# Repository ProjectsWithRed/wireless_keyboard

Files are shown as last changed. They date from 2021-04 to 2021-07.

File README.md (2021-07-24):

# Arduino custom wireless keyboard

There is a [video](https://youtu.be/N5rOW5Bu1kc) associated with this repo, I highly recommend you watch it if you are going to use this repo.

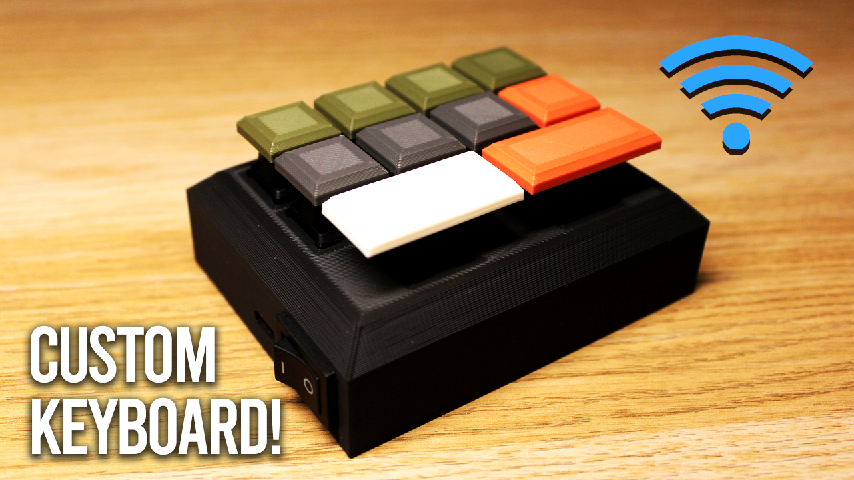
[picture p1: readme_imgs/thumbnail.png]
Video (https://youtu.be/N5rOW5Bu1kc "Arduino wireless keyboard")


# How to use

## Libraries needed

*Installed directly from the Arduino library manager.

- `RF24` by TMRh20.
- `Button` by Michael Adams.

## For the transmitter

- This is the micro-controller (MC) that will be running on battery and where all the buttons will be connected to. This needs to be a low current consuming MC and one that ideally meets the number of inputs pins to match the number buttons you are going to have.
- I highly recommend the Attiny MCs, such as the Attiny85 (8 pins), Attiny84 (14 pins), or the Attiny88 (28 pins).
- Changes you need to make to the code (`/transmitter`):
    - The `CE and CSN` pin numbers to match your connections, these could be any GPIO pins in your MC.
    - `MAX_SHORTCUT_KEYS`, this is the maximum number of characters a keyboard shortcut/sequence can be. This is specified so only the required number of bytes are sent through the radio signal.
    - The `BUTTONS_INFO` array. Each button element is made up of two values, the first is the pin number the button is connected to your MC. The second is a string of characters seperated by spaces. The characters are represented by their decimal/int values, which can be found [here](http://www.asciitable.com/) and [here](https://www.arduino.cc/reference/en/language/functions/usb/keyboard/keyboardmodifiers/). Make sure you don't go over your `MAX_SHORTCUT_KEYS` in the string of keys, if more keys are required, simply increase `MAX_SHORTCUT_KEYS`.

## For the Receiver

- Any MC can be used here with USB cable connection, and one that has HID support so you can easily use the Arduino Keyboard library with no issues. I recommend the Pro Micro MC.
- Changes you need to make to the code (`/receiver`):
    - The only change you need to make is if you changed the `MAX_SHORTCUT_KEYS` in the transmitter side, if you did, make sure the `MAX_SHORTCUT_KEYS` matches.

## For 3D printing

Please refer to the `/3d_models` directory.

# Components

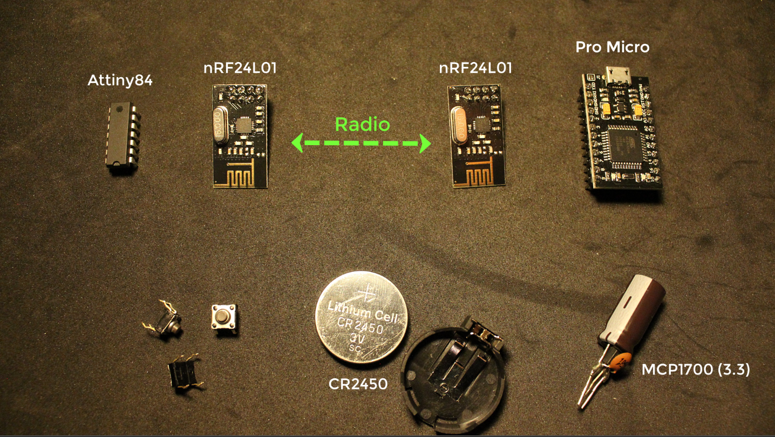
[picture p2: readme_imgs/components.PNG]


# Wiring

## Transmitter
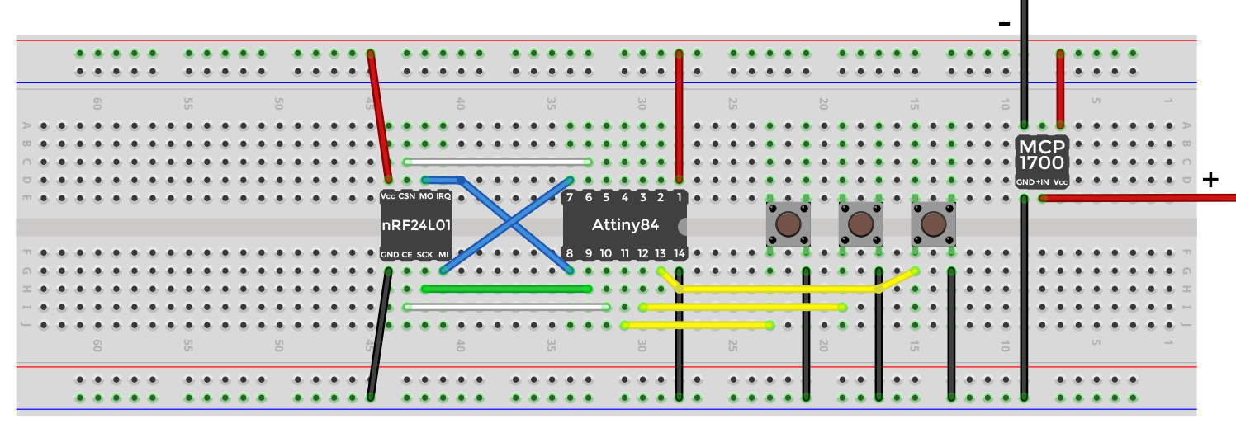
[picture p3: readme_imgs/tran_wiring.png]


## Receiver
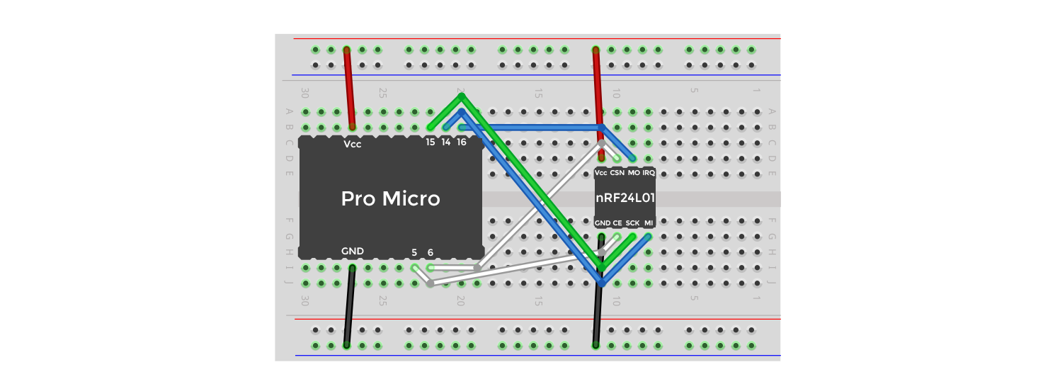
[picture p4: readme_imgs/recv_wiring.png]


# How to upload code to Attiny MCs

- The Attiny MCs can be programmed just like any Arduino and it's very easy to upload code to them.
- You just need a USBASP adapter, then simply make the connections as shown in the image below.

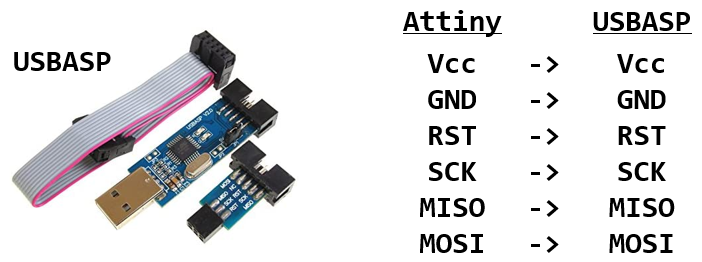
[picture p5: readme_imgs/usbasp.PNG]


- You will also need to install the Attiny boards using the [AttinyCore](https://github.com/SpenceKonde/ATTinyCore) board manager by placing this link `http://drazzy.com/package_drazzy.com_index.json` to your "Additional Boards Manager URLs", which can be accessed in `File > Preferences`.

- From `Tools > Board`, choose your Attiny board with the no bootloader option.
- Then go to `Tools > Programmer` and choose `USBasp (ATTinyCore)`, and then press `Tools > Burn Bootloader`.
- Then to simply upload code, use `Sketch > Upload Using Programmer`.

- You can use stripboards with some wires to make uploading code to the Attiny MCs more convenient:

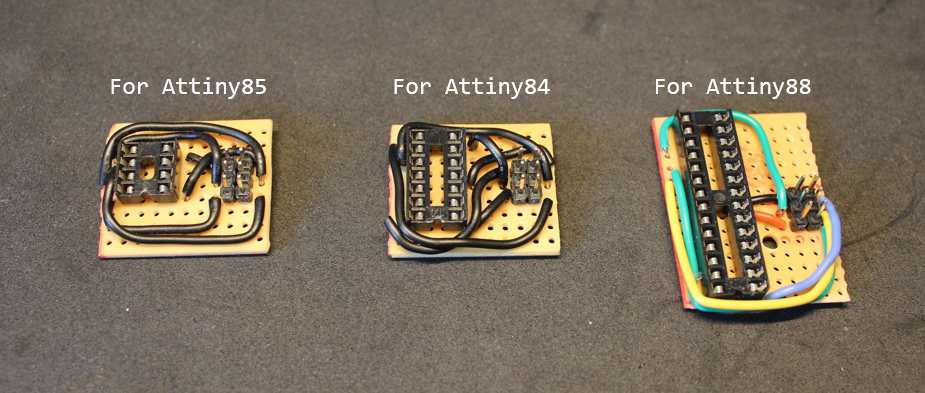
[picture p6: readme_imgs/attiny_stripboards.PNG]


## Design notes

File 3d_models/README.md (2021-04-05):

# 3D models

Please note, these models only work for MX Cherry switches.

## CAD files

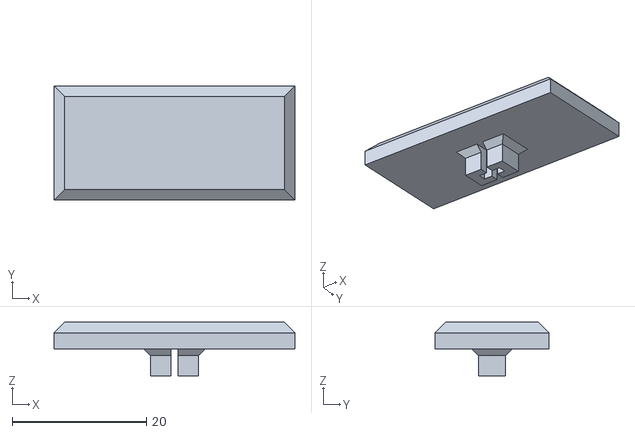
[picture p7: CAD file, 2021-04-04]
3d_models/keyCap_2x1.stl
35.9 x 17.0 x 8.00

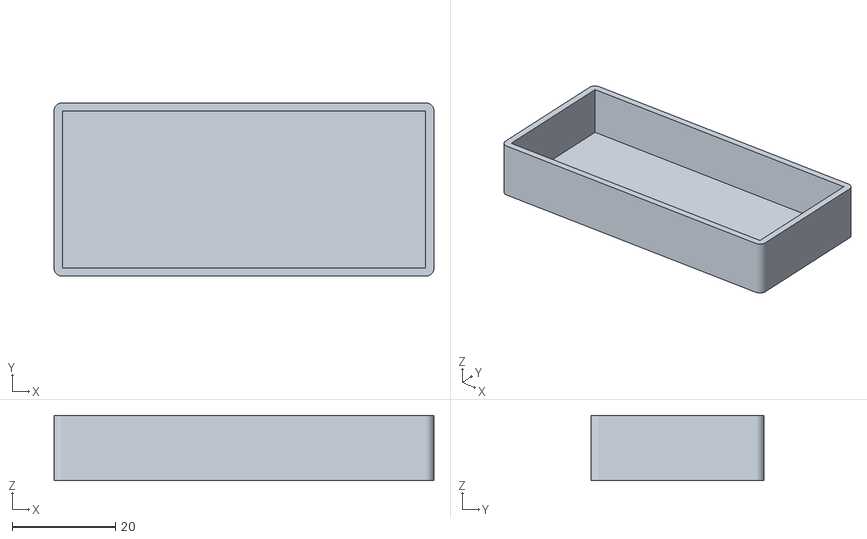
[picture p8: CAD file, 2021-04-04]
3d_models/recv_housing.stl
73.6 x 33.6 x 12.6

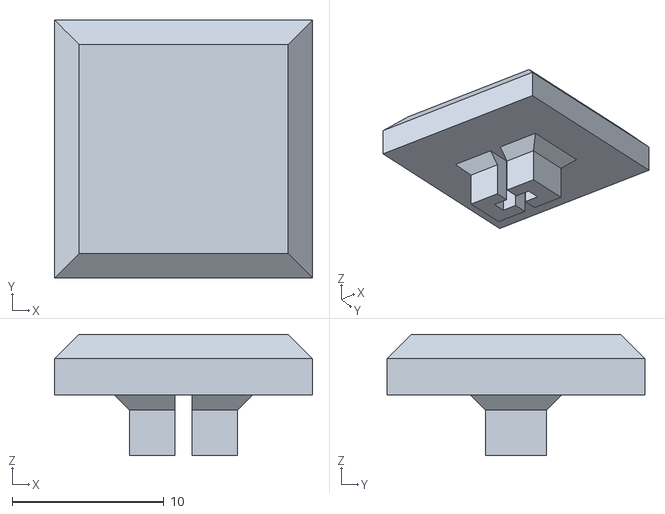
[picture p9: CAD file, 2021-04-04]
3d_models/keyCap_1x1.stl
17.0 x 17.0 x 8.00

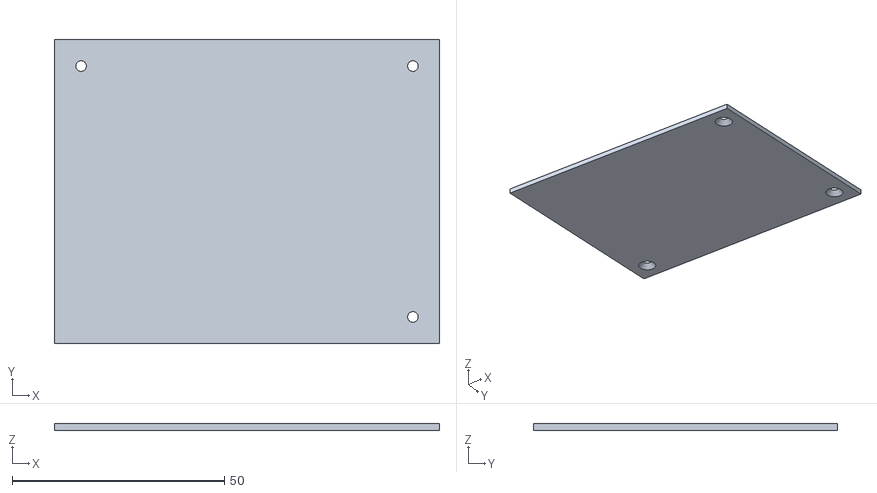
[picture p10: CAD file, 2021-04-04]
3d_models/lid.stl
90.6 x 71.5 x 1.60

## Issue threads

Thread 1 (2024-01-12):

Making smaller version of this wireless keyboard by ProjectsWithRed

liamwheat, 2024-01-12:
Hello
So to summarize, I am attempting to make an identical keyboard to the one beautifully crafted by ProjectsWithRed,  Mine however will feature only a single button and uses all the exact same components apart from the ATtiny84 as I am using the smaller ATtiny85  instead!

I have therefore used the same code and libraries and adjusted the wiring and code (pins and input commands) for my single button which I want to command an input of "LCTRL+e"repeated 3 times. when pressed once.

 To my knowledge I followed as carefully as possible all steps involved however testing the button I had no luck.
As mentioned I have used all the same parts, apart from using the smaller Attiny85 and single button.

Included in my post here I have attached my circuit diagrams and my code which I uploaded to the transmitter and receiver.
also when uploading the code to the Attiny85 i used an Arduino uno as ISP, and followed online guides as to how to correctly upload code to the Attiny with this method. I believe I did this correctly.

Hopefully ProjectsWithRed can help me with this and anyone else looking to do similar can also see the fix.

*sidenote, my code for the buttons command is currently set as {{5, "128 101"},  (pin 5, LCTRL e)  I am aware this currently does not include the repeat function i wish to add so that the single press of the button will cause it to loop/repeat 'LCTRL +e'  3 times.  I am unsure of how to do that and so need help with this. But for now the problem stands, I cannot get it to show any command.
It could be a wiring issue --perhaps I've made an error with the ATtiny pins I've used for the button and  transmitter, or perhaps my code adjustments are incorrect.

Your help is greatly appreciated.

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

[attiny85  transmittrer code.txt](https://github.com/ProjectsWithRed/wireless_keyboard/files/13924002/attiny85.transmittrer.code.txt)

[Promiccro reciever code.txt](https://github.com/ProjectsWithRed/wireless_keyboard/files/13924010/Promiccro.reciever.code.txt)

**### _Attiny transmitter code:_**

```
#include "SPI.h"
#include "RF24.h"

#include <Button.h>*

// Radio, choose any pins on your micro-controller to use as the CE and CSN pins.
#define CE_PIN 2
#define CSN_PIN 3

const uint8_t ADDRESS[6] = "CKeyB";

// Maximum number of keys a shortcut can be, or max number of keys to send through the NRF24L01 per button.
// This needs to match with the receiver side.
const int MAX_SHORTCUT_KEYS = 4;

const int BTN_SHORTCUT_SIZE = (3 * MAX_SHORTCUT_KEYS) + (MAX_SHORTCUT_KEYS - 1) + 1;

struct ButtonInfo {
    int btnPin;
    char btnShortcut[BTN_SHORTCUT_SIZE];
};

// All keys are represented using their ASCII decimal/int value. This can be found here: www.asciitable.com
// First specify the pin number, then seperate each key for that button in a string by a space.
const ButtonInfo BUTTONS_INFO[] = {{5, "128 101"},
                                   };

const int N_BUTTONS = sizeof(BUTTONS_INFO) / sizeof(BUTTONS_INFO[0]);

const uint16_t DEBOUNCE_MS = 10;

RF24 radio(CE_PIN, CSN_PIN);

Button *buttonObjs[N_BUTTONS];

void initRadio() {

    if (!radio.begin()) {
        while (1) {}
    }

    radio.setPALevel(RF24_PA_LOW);
    radio.setPayloadSize(BTN_SHORTCUT_SIZE);
    radio.openWritingPipe(ADDRESS);
    radio.setDataRate(RF24_1MBPS);

    radio.stopListening();
}

void initButtons() {
    for(int i = 0; i < N_BUTTONS; i++) {
        ButtonInfo btnInfo = BUTTONS_INFO[i];
        buttonObjs[i] -> begin();
    }
}

void setup() {

    initRadio();
    initButtons();

}

void loop() {

    // If any button pressed, then send the button keys through radio using the nRF24L01.
    for(int i = 0; i < N_BUTTONS; i++) {
        if(buttonObjs[i] -> pressed()) {
            ButtonInfo btnInfo = BUTTONS_INFO[i];
    
            radio.write(&btnInfo.btnShortcut, sizeof(btnInfo.btnShortcut));
    
            break;
        }
    }
}

```

### **_Pro-micro receiver code:_**

```
#include "SPI.h"
#include "RF24.h"

#include <Keyboard.h>

#define CE_PIN 5
#define CSN_PIN 6

RF24 radio(CE_PIN, CSN_PIN);

uint8_t ADDRESS[6] = "CKeyB";

// Maximum number of keys a shortcut can be, or max number of keys to send through the NRF24L01 per button.
// This needs to match with the transmitter side.
const int MAX_SHORTCUT_KEYS = 4;

const int BTN_SHORTCUT_SIZE = (3 * MAX_SHORTCUT_KEYS) + (MAX_SHORTCUT_KEYS - 1) + 1;

char btnShortcut[BTN_SHORTCUT_SIZE];

char * key;
int keyInt;

void initRadio() {
    if (!radio.begin()) {
        while (1) {}
    }

    radio.setPALevel(RF24_PA_LOW);
    radio.setPayloadSize(BTN_SHORTCUT_SIZE);
    radio.openReadingPipe(1, ADDRESS);
    radio.setDataRate(RF24_1MBPS);

    radio.startListening();
}

void setup() {
    Keyboard.begin();

    initRadio();
}

void loop() {
    if (radio.available()) {
        radio.read(&btnShortcut, sizeof(btnShortcut));

        // Excract each key integer value from the incoming string and press each button.
        key = strtok(btnShortcut, " ");

        while(key != NULL) {
            keyInt = atoi(key);
            Keyboard.press(keyInt);
    
            key = strtok(NULL, " ");
        }

        delay(10);
        Keyboard.releaseAll();
    }
}
```

ProjectsWithRed, 2024-01-21:
After a quick look at your wiring diagram, I can see that on the Attiny85, the MISO and MOSI pins have been swapped around.

ProjectsWithRed, 2024-01-22:
You need to check the datasheet for your specific Attiny to make sure.

liamwheat, 2024-01-26:
Hi i have now confirmed the pins for my attiny85 and rewired accordingly. However still no luck for me i'm afraid.
Does the code look all good to you?
I've also attached a picture how im powering it, the same as your video 2, 3v coin cells.  Just wanted to check it looks alright with the capacitors.

Also for my single button -- I want to command an input of "LCTRL+e"repeated 3 times, when pressed once. would you be able to help me with that? the normal LCTRL + e part i have used your method for and tweaked the index, but the repeat part im not sure how to do.

Best regards

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

ProjectsWithRed, 2024-01-27:
- I think it might be because pin 5 on the Attiny85 is a reset pin. I would have suggested try a different pin, but you don't have any other pins left to try on the Attiny85. Do you have the Attiny84 available?
- In terms of the code.
    - The `CE` and `CSN` pins are incorrectly specified. According to your breadboard image, `CE_PIN` should be 3, and `CSN_PIN` should be 4.
    - You seem to have delete a line on the transmitter code, in the `initButtons()` function line 64, `buttonObjs[i] = new Button(btnInfo.btnPin, DEBOUNCE_MS);`.
- Double check all wiring, especially the soldered wires, test that they are all working as expected.

If none of these changes work, try point 1, which might just be the issue.

ProjectsWithRed, 2024-02-10:
Removing line 64 will for sure make the code not work, so if this has been the case then that might very well be the core of the issue. Can you just upload anything you know that will work to the Attiny so you can confirm everything else is good to go, could be a simple blinking LED example.
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
liamwheat, 2024-02-16:
Hello, sooo.. here I have copied the error I am getting and a screenshot of the highlighted line 64. the code has not been edited it is copied directly from your project. Hopefully this could give us an idea as  to whats going wrong for me? Kind regards.

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

Below is the error messages:

Arduino: 1.8.19 (Windows 10), Board: "Arduino Uno"
C:\Users\liam_\OneDrive\Documents\Arduino\Attiny_84_transmitter_code\Attiny_84_transmitter_code.ino: In function 'void initButtons()':

Attiny_84_transmitter_code:64:63: error: no matching function for call to 'Button::Button(int&, const uint16_t&)'

         buttonObjs[i] = new Button(btnInfo.btnPin, DEBOUNCE_MS);

                                                               ^

In file included from C:\Users\liam_\OneDrive\Documents\Arduino\Attiny_84_transmitter_code\Attiny_84_transmitter_code.ino:4:0:

C:\Users\liam_\OneDrive\Documents\Arduino\libraries\Button/Button.h:14:3: note: candidate: Button::Button(uint8_t)

   Button(uint8_t pin);

   ^~~~~~

C:\Users\liam_\OneDrive\Documents\Arduino\libraries\Button/Button.h:14:3: note:   candidate expects 1 argument, 2 provided

C:\Users\liam_\OneDrive\Documents\Arduino\libraries\Button/Button.h:11:7: note: candidate: constexpr Button::Button(const Button&)

 class Button

       ^~~~~~

C:\Users\liam_\OneDrive\Documents\Arduino\libraries\Button/Button.h:11:7: note:   candidate expects 1 argument, 2 provided

C:\Users\liam_\OneDrive\Documents\Arduino\libraries\Button/Button.h:11:7: note: candidate: constexpr Button::Button(Button&&)

C:\Users\liam_\OneDrive\Documents\Arduino\libraries\Button/Button.h:11:7: note:   candidate expects 1 argument, 2 provided

exit status 1

no matching function for call to 'Button::Button(int&, const uint16_t&)'

This report would have more information with
"Show verbose output during compilation"
option enabled in File -> Preferences.

ProjectsWithRed, 2024-02-17:
Have you installed the `Button` library by Michael Adams?

liamwheat, 2024-02-29:
Sorry for slow reply, I've been on leave.

Yes i've just double checked and i can confirm button library by Micheal adams is installed

liamwheat, 2024-02-29:
I have noticed that in your video button library shows orange in colour, mine is however grey. Comparison below.
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

liamwheat, 2024-02-29:
Okay ive just managed to link the library and its now orange. Now when attempting to erifiy the code to upload i get alot of errors associated with SPI.

Small snipit of the error below:

C:\Program Files (x86)\Arduino\hardware\arduino\avr\libraries\SPI\src/SPI.h:310:55: error: 'SPIE' was not declared in this scope
   inline static void detachInterrupt() { SPCR &= ~_BV(SPIE); }
C:\Program Files (x86)\Arduino\hardware\arduino\avr\libraries\SPI\src/SPI.h:310:55: note: suggested alternative: 'ACIE'
exit status 1
Error compiling for board ATtiny24/44/84.

Could it be that the SPI library is not installed? where did you install/ find this library?. I do have the RF24 library installed as I followed your video, however SPI library installation was not covered.

As always kind regards and thankyou for checking

ProjectsWithRed, 2024-03-02:
Are you changing the Tools>Programmer to `USBasp (ATTinyCore)` and selecting Attiny84 no bootloader as the microcontroller in the Arduino IDE? Are you using this [ATTinyCore](https://github.com/SpenceKonde/ATTinyCore) board manager?

liamwheat, 2024-03-05:
My method for uploading the code is a bit earlier in our discussion, I used the arduino uno as ISP.  Have a quick check back, as  I've put step by step my actions by the book I believe. I do have an USBasp adapter, but it was requiring more and more things to upload the code, so I went with the arduino uno solution following this guide:

https://www.youtube.com/watch?v=dtPGMTBdDoA&ab_channel=AhmadLogs

ProjectsWithRed, 2024-03-06:
The issue is with the micro-controller selection and upload, I have not uploaded code to the Attiny in that way so I can't help in that regard.

liamwheat, 2024-03-12:
Would you be able to provide a guide on how you uploaded your code onto the attiny using the USBasp.?  I do own one, but I've searched hard to find a concrete method but not sure how to do it.  If you could give me a stepped guide including components i could give it a go.
kind regards and as always thankyou for your support so far

ProjectsWithRed, 2024-03-15:
The instructions for that is in the readme of this repository, found [here](https://github.com/ProjectsWithRed/wireless_keyboard?tab=readme-ov-file#how-to-upload-code-to-attiny-mcs)

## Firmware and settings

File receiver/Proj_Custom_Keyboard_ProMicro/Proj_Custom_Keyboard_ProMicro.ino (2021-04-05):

#include "SPI.h"
#include "RF24.h"

#include <Keyboard.h>

#define CE_PIN 5
#define CSN_PIN 6

RF24 radio(CE_PIN, CSN_PIN);


uint8_t ADDRESS[6] = "CKeyB";


// Maximum number of keys a shortcut can be, or max number of keys to send through the NRF24L01 per button.
// This needs to match with the transmitter side.
const int MAX_SHORTCUT_KEYS = 4;


const int BTN_SHORTCUT_SIZE = (3 * MAX_SHORTCUT_KEYS) + (MAX_SHORTCUT_KEYS - 1) + 1;

char btnShortcut[BTN_SHORTCUT_SIZE];

char * key;
int keyInt;



void initRadio() {
    if (!radio.begin()) {
        while (1) {}
    }
    
    radio.setPALevel(RF24_PA_LOW);
    radio.setPayloadSize(BTN_SHORTCUT_SIZE);
    radio.openReadingPipe(1, ADDRESS);
    radio.setDataRate(RF24_1MBPS);
    
    radio.startListening();
}



void setup() {
    Keyboard.begin();
    
    initRadio();
}



void loop() {
    if (radio.available()) {
        radio.read(&btnShortcut, sizeof(btnShortcut));
        
        // Excract each key integer value from the incoming string and press each button.
        key = strtok(btnShortcut, " ");
        
        while(key != NULL) {
            keyInt = atoi(key);    
            Keyboard.press(keyInt);
            
            key = strtok(NULL, " ");
        }
        
        delay(10);
        Keyboard.releaseAll();
    }
}

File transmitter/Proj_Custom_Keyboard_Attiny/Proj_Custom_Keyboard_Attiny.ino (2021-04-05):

#include "SPI.h"
#include "RF24.h"

#include <Button.h>


// Radio, choose any pins on your micro-controller to use as the CE and CSN pins.
#define CE_PIN 3
#define CSN_PIN 7

const uint8_t ADDRESS[6] = "CKeyB";


// Maximum number of keys a shortcut can be, or max number of keys to send through the NRF24L01 per button.
// This needs to match with the receiver side.
const int MAX_SHORTCUT_KEYS = 4;


const int BTN_SHORTCUT_SIZE = (3 * MAX_SHORTCUT_KEYS) + (MAX_SHORTCUT_KEYS - 1) + 1;

struct ButtonInfo {
    int btnPin;
    char btnShortcut[BTN_SHORTCUT_SIZE];
};


// All keys are represented using their ASCII decimal/int value. This can be found here: www.asciitable.com
// First specify the pin number, then seperate each key for that button in a string by a space.
const ButtonInfo BUTTONS_INFO[] = {{2, "80 119 82"},
                                   {1, "128 99"},
                                   {0, "128 118"},
                                   };


const int N_BUTTONS = sizeof(BUTTONS_INFO) / sizeof(BUTTONS_INFO[0]);

const uint16_t DEBOUNCE_MS = 10;


RF24 radio(CE_PIN, CSN_PIN);


Button *buttonObjs[N_BUTTONS];



void initRadio() {
    
    if (!radio.begin()) {
        while (1) {}
    }

    radio.setPALevel(RF24_PA_LOW);
    radio.setPayloadSize(BTN_SHORTCUT_SIZE);
    radio.openWritingPipe(ADDRESS);
    radio.setDataRate(RF24_1MBPS);
    
    radio.stopListening();
}

void initButtons() {
    for(int i = 0; i < N_BUTTONS; i++) {
        ButtonInfo btnInfo = BUTTONS_INFO[i];
        buttonObjs[i] = new Button(btnInfo.btnPin, DEBOUNCE_MS);
        buttonObjs[i] -> begin();
    }
}


void setup() {

    initRadio();
    initButtons();
    
}

void loop() {

    // If any button pressed, then send the button keys through radio using the nRF24L01.
    for(int i = 0; i < N_BUTTONS; i++) {
        if(buttonObjs[i] -> pressed()) {
            ButtonInfo btnInfo = BUTTONS_INFO[i];
            
            radio.write(&btnInfo.btnShortcut, sizeof(btnInfo.btnShortcut));
            
            break;
        }
    }
}

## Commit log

2021-04-04 Add trans and recv code and wiring images.
2021-04-04 Add 3d models.
    [keyCap_1x1.stl, keyCap_2x1.stl, lid.stl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]
2021-07-24 Add the Button library to the libraries needed.
